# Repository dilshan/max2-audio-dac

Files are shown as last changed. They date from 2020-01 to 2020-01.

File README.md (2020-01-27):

# 24-bit Stereo Audio DAC for Raspberry Pi



MAX-II DAC Module

This is a 24-bit stereo DAC, which is specifically built for Raspberry Pi boards. This R-2R ladder DAC is developing around Intel / Altera *EPM240T100C5N* CPLD.

DAC which described in this repo can directly connect with the I2S interface of Raspberry Pi boards. The recommended supply voltage for this DAC is 5V to 8V.

The *MCP602* opamp of this module is capable to drive headphone directly. An external AF power amplifier must pair with this module to obtain a higher output power.

This repository contains all the files and binaries to build DAC, which including *Intel Quartus* Project files, Raspberry Pi Device Tree Overlays, etc.

This is certified open-source hardware project. All the content of this project are distributed under the terms of the following license:

-   Hardware License: [CC BY 4.0](https://creativecommons.org/licenses/by/4.0/)
-   Software License: [MIT](https://github.com/dilshan/max2-audio-dac/blob/master/LICENSE)
-   [Documentation](https://github.com/dilshan/max2-audio-dac/wiki) License: [CC BY 4.0](https://creativecommons.org/licenses/by/4.0/)

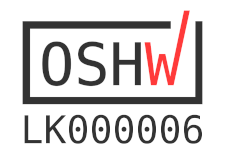
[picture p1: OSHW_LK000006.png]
OSHW-LK000006 (https://certification.oshwa.org/lk000006.html)


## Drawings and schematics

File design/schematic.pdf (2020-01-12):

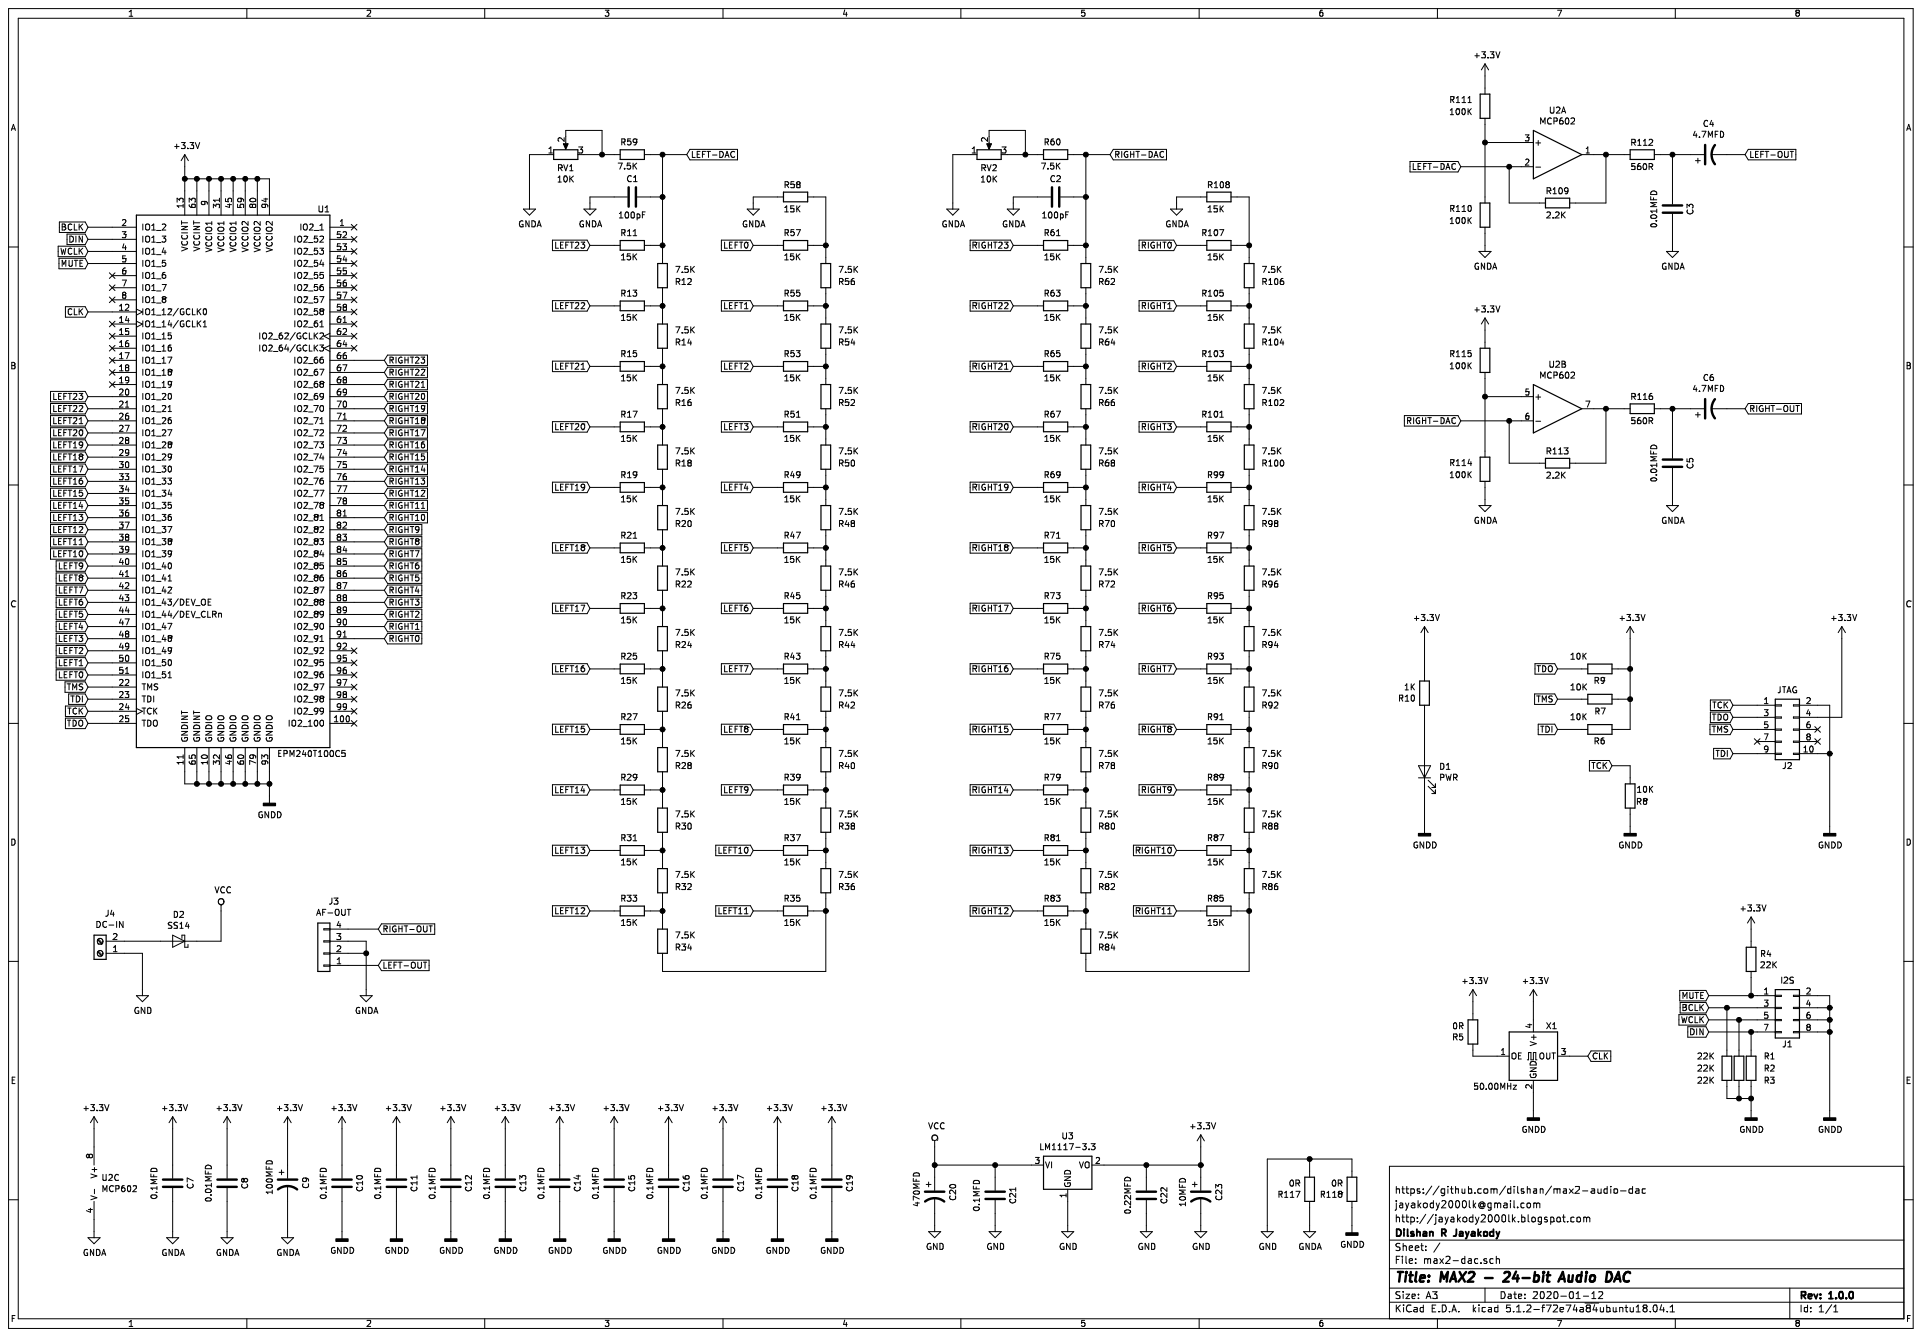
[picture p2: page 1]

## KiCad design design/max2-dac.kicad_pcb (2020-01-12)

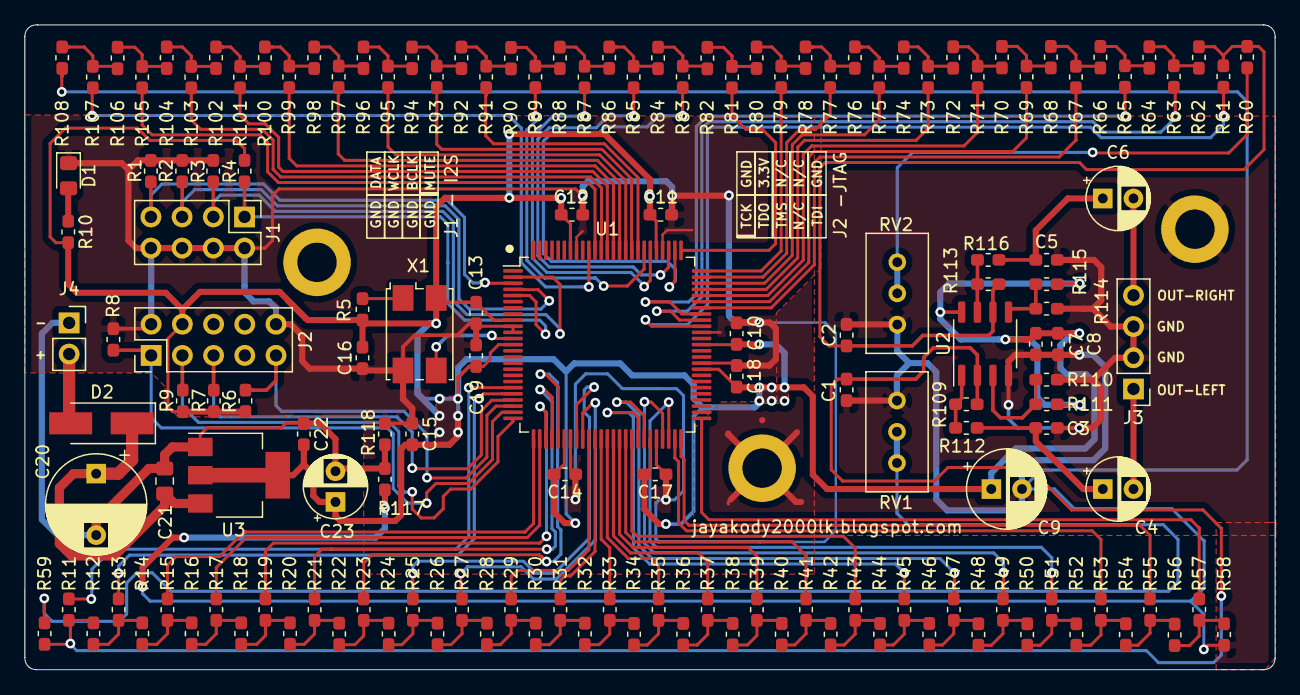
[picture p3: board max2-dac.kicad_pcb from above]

Board: 2 copper layers, 101.8 x 52.5 mm, 156 parts (0 on the bottom side), 123 nets.

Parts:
 : MountingHole_3.2mm_M3_ISO14580_Pad
 #2,  #3: MountingHole_3.2mm_M3_ISO14580_Pad
C1, C2: 100pF; C_0603_1608Metric_Pad1.05x0.95mm_HandSolder
C3, C5, C8: 0.01MFD; C_0603_1608Metric_Pad1.05x0.95mm_HandSolder
C4, C6: 4.7MFD; CP_Radial_D5.0mm_P2.50mm
C7, C10, C11, C12, C13, C14, C15, C16, C17, C18, C19: 0.1MFD; C_0603_1608Metric_Pad1.05x0.95mm_HandSolder
C9: 100MFD; CP_Radial_D6.3mm_P2.50mm
C20: 470MFD; CP_Radial_D8.0mm_P5.00mm
C21: 0.1MFD; C_0805_2012Metric_Pad1.15x1.40mm_HandSolder
C22: 0.22MFD; C_0603_1608Metric_Pad1.05x0.95mm_HandSolder
C23: 10MFD; CP_Radial_D5.0mm_P2.50mm
D1: PWR; LED_0805_2012Metric_Pad1.15x1.40mm_HandSolder
D2: SS14; D_SMA_Handsoldering
J1: I2S; PinHeader_2x04_P2.54mm_Vertical
J2: JTAG; PinHeader_2x05_P2.54mm_Vertical
J3: AF-OUT; PinHeader_1x04_P2.54mm_Vertical
J4: DC-IN; PinSocket_1x02_P2.54mm_Vertical
R1, R2, R3, R4: 22K; R_0603_1608Metric_Pad1.05x0.95mm_HandSolder
R5, R117, R118: 0R; R_0603_1608Metric_Pad1.05x0.95mm_HandSolder
R6, R7, R8, R9: 10K; R_0603_1608Metric_Pad1.05x0.95mm_HandSolder
R10: 1K; R_0603_1608Metric_Pad1.05x0.95mm_HandSolder
R11, R13, R15, R17, R19, R21, R23, R25, R27, R29, R31, R33, R35, R37, R39, R41, R43, R45, R47, R49, R51, R53, R55, R57, R58, R61, R63, R65, R67, R69, R71, R73, R75, R77, R79, R81, R83, R85, R87, R89, R91, R93, R95, R97, R99, R101, R103, R105, R107, R108: 15K; R_0603_1608Metric_Pad1.05x0.95mm_HandSolder
R12, R14, R16, R18, R20, R22, R24, R26, R28, R30, R32, R34, R36, R38, R40, R42, R44, R46, R48, R50, R52, R54, R56, R59, R60, R62, R64, R66, R68, R70, R72, R74, R76, R78, R80, R82, R84, R86, R88, R90, R92, R94, R96, R98, R100, R102, R104, R106: 7.5K; R_0603_1608Metric_Pad1.05x0.95mm_HandSolder
R109, R113: 2.2K; R_0603_1608Metric_Pad1.05x0.95mm_HandSolder
R110, R111, R114, R115: 100K; R_0603_1608Metric_Pad1.05x0.95mm_HandSolder
R112, R116: 560R; R_0603_1608Metric_Pad1.05x0.95mm_HandSolder
RV1, RV2: 10K; Potentiometer_Bourns_3296W_Vertical
U1: EPM240T100C5; LQFP-100_14x14mm_P0.5mm
U2: MCP602; SO-8_3.9x4.9mm_P1.27mm
U3: LM1117-3.3; SOT-223-3_TabPin2
X1: 50.00MHz; Crystal_SMD_7050-4Pin_7.0x5.0mm

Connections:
+3V3: C7.2, C8.2, C9.1, C10.2, C11.2, C12.2, C13.2, C14.2, C15.2, C16.2, C17.2, C18.2, C19.2, C22.2, C23.1, J2.4, R4.1, R5.2, R6.2, R7.1, R9.2, R10.2, R111.2, R115.2, U1.9, U1.13, U1.31, U1.45, U1.59, U1.63, U1.80, U1.94, U2.8, U3.2, X1.4
BCLK: J1.3, R3.1, U1.2
CLK: U1.12, X1.3
DIN: J1.7, R1.1, U1.3
GND: C20.2, C21.1, C22.1, C23.2, J4.1, R117.2, R118.2, U3.1
GNDA: #2.1, #3.1, C1.2, C2.2, C3.1, C5.1, C7.1, C8.1, C9.2, J3.2, J3.3, R58.2, R108.2, R110.1, R114.1, R117.1, RV1.1, RV2.1, U2.4
GNDD: C10.1, C11.1, C12.1, C13.1, C14.1, C15.1, C16.1, C17.1, C18.1, C19.1, D1.1, J1.2, J1.4, J1.6, J1.8, J2.2, J2.10, R1.2, R2.2, R3.2, R8.1, R118.1, U1.10, U1.11, U1.32, U1.46, U1.60, U1.65, U1.79, U1.93, X1.2
LEFT0: R57.1, U1.51
LEFT1: R55.1, U1.50
LEFT2: R53.1, U1.49
LEFT3: R51.1, U1.48
LEFT4: R49.1, U1.47
LEFT5: R47.1, U1.44
LEFT6: R45.1, U1.43
LEFT7: R43.1, U1.42
LEFT8: R41.1, U1.41
LEFT9: R39.1, U1.40
LEFT10: R37.1, U1.39
LEFT11: R35.1, U1.38
LEFT12: R33.1, U1.37
LEFT13: R31.1, U1.36
LEFT14: R29.1, U1.35
LEFT15: R27.1, U1.34
LEFT16: R25.1, U1.33
LEFT17: R23.1, U1.30
LEFT18: R21.1, U1.29
LEFT19: R19.1, U1.28
LEFT20: R17.1, U1.27
LEFT21: R15.1, U1.26
LEFT22: R13.1, U1.21
LEFT23: R11.1, U1.20
LEFT-DAC: C1.1, R11.2, R12.1, R59.2, R109.2, U2.2
LEFT-OUT: C4.2, J3.1
MUTE: J1.1, R4.2, U1.5
unnamed: C3.2, C4.1, R112.1
unnamed: C5.2, C6.1, R116.1
unnamed: D1.2, R10.1
unnamed: D2.2, J4.2
unnamed: R5.1, X1.1
unnamed: R12.2, R13.2, R14.1
unnamed: R14.2, R15.2, R16.1
unnamed: R16.2, R17.2, R18.1
unnamed: R18.2, R19.2, R20.1
unnamed: R20.2, R21.2, R22.1
unnamed: R22.2, R23.2, R24.1
unnamed: R24.2, R25.2, R26.1
unnamed: R26.2, R27.2, R28.1
unnamed: R28.2, R29.2, R30.1
unnamed: R30.2, R31.2, R32.1
unnamed: R32.2, R33.2, R34.1
unnamed: R34.2, R35.2, R36.2
unnamed: R36.1, R37.2, R38.2
unnamed: R38.1, R39.2, R40.2
unnamed: R40.1, R41.2, R42.2
unnamed: R42.1, R43.2, R44.2
unnamed: R44.1, R45.2, R46.2
unnamed: R46.1, R47.2, R48.2
unnamed: R48.1, R49.2, R50.2
unnamed: R50.1, R51.2, R52.2
unnamed: R52.1, R53.2, R54.2
unnamed: R54.1, R55.2, R56.2
unnamed: R56.1, R57.2, R58.1
unnamed: R59.1, RV1.2, RV1.3
unnamed: R60.1, RV2.2, RV2.3
unnamed: R62.2, R63.2, R64.1
unnamed: R64.2, R65.2, R66.1
unnamed: R66.2, R67.2, R68.1
unnamed: R68.2, R69.2, R70.1
unnamed: R70.2, R71.2, R72.1
unnamed: R72.2, R73.2, R74.1
unnamed: R74.2, R75.2, R76.1
unnamed: R76.2, R77.2, R78.1
unnamed: R78.2, R79.2, R80.1
unnamed: R80.2, R81.2, R82.1
unnamed: R82.2, R83.2, R84.1
unnamed: R84.2, R85.2, R86.2
unnamed: R86.1, R87.2, R88.2
unnamed: R88.1, R89.2, R90.2
unnamed: R90.1, R91.2, R92.2
unnamed: R92.1, R93.2, R94.2
unnamed: R94.1, R95.2, R96.2
unnamed: R96.1, R97.2, R98.2
unnamed: R100.1, R101.2, R102.2
unnamed: R98.1, R99.2, R100.2
unnamed: R102.1, R103.2, R104.2
unnamed: R104.1, R105.2, R106.2
unnamed: R106.1, R107.2, R108.1
unnamed: R109.1, R112.2, U2.1
unnamed: R110.2, R111.1, U2.3
unnamed: R113.1, R116.2, U2.7
unnamed: R114.2, R115.1, U2.5
RIGHT0: R107.1, U1.91
RIGHT1: R105.1, U1.90
RIGHT2: R103.1, U1.89
RIGHT3: R101.1, U1.88
RIGHT4: R99.1, U1.87
RIGHT5: R97.1, U1.86
RIGHT6: R95.1, U1.85
RIGHT7: R93.1, U1.84
RIGHT8: R91.1, U1.83
RIGHT9: R89.1, U1.82
RIGHT10: R87.1, U1.81
RIGHT11: R85.1, U1.78
RIGHT12: R83.1, U1.77
RIGHT13: R81.1, U1.76
RIGHT14: R79.1, U1.75
RIGHT15: R77.1, U1.74
RIGHT16: R75.1, U1.73
RIGHT17: R73.1, U1.72
RIGHT18: R71.1, U1.71
RIGHT19: R69.1, U1.70
RIGHT20: R67.1, U1.69
RIGHT21: R65.1, U1.68
RIGHT22: R63.1, U1.67
RIGHT23: R61.1, U1.66
RIGHT-DAC: C2.1, R60.2, R61.2, R62.1, R113.2, U2.6
RIGHT-OUT: C6.2, J3.4
TCK: J2.1, R8.2, U1.24
TDI: J2.9, R6.1, U1.23
TDO: J2.3, R9.1, U1.25
TMS: J2.5, R7.2, U1.22
VCC: C20.1, C21.2, D2.1, U3.3
WCLK: J1.5, R2.1, U1.4

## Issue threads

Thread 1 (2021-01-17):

question

munjeni, 2021-01-17:
Hallo!

I very interested in building some variants and want to ask for your experience if possible. I have found 3 variants:

1. https://audiophilediyer.com/discrete-r-2r-dac-hat-for-raspberry-pi/
2. http://puredsd.ru
3. http://www.audiodesignguide.com/DSC2/index.html

Can you tell me did you triend all 3 variants and what you think in your opinions is the best one (related to r2r implementation only)? Thanks for response!

smdjeff, 2022-09-11:
Ladder DACs go back to at least the 1950s.
The Pi hat looks to be the cleanest implementation if you're after audio.
The other two versions use  595s as IO expanders so they might be related.
And this one by @dilshan is a bit simpler(cleaner) as it uses GPIOs directly.

munjeni, 2023-01-14:
I think r2r is at the last, the better one is that which have current mode moving average implementation as done in DSC dac, a lot less noise in comparation to r2r technology, but it reguire DSD bitstream. We have done direct digital power dac DDPD with success and amazing sound, more info https://www.diyaudio.com/community/threads/ct7302pl.357501/page-4

natil79, 2024-07-27:
Hi, nice work,, I would like to build it, but I would like to use it whitout Raspberry pi, could you tell me what frequency I2S source it can handle?

Thank you for your help!

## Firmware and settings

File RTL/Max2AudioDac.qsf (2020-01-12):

# -------------------------------------------------------------------------- #
#
# Copyright (C) 2018  Intel Corporation. All rights reserved.
# Your use of Intel Corporation's design tools, logic functions 
# and other software and tools, and its AMPP partner logic 
# functions, and any output files from any of the foregoing 
# (including device programming or simulation files), and any 
# associated documentation or information are expressly subject 
# to the terms and conditions of the Intel Program License 
# Subscription Agreement, the Intel Quartus Prime License Agreement,
# the Intel FPGA IP License Agreement, or other applicable license
# agreement, including, without limitation, that your use is for
# the sole purpose of programming logic devices manufactured by
# Intel and sold by Intel or its authorized distributors.  Please
# refer to the applicable agreement for further details.
#
# -------------------------------------------------------------------------- #
#
# Quartus Prime
# Version 18.1.0 Build 625 09/12/2018 SJ Lite Edition
# Date created = 13:50:59  August 08, 2019
#
# -------------------------------------------------------------------------- #
#
# Notes:
#
# 1) The default values for assignments are stored in the file:
#		Max2AudioDac_assignment_defaults.qdf
#    If this file doesn't exist, see file:
#		assignment_defaults.qdf
#
# 2) Altera recommends that you do not modify this file. This
#    file is updated automatically by the Quartus Prime software
#    and any changes you make may be lost or overwritten.
#
# -------------------------------------------------------------------------- #


set_global_assignment -name FAMILY "MAX II"
set_global_assignment -name DEVICE EPM240T100C5
set_global_assignment -name TOP_LEVEL_ENTITY Max2AudioDac
set_global_assignment -name ORIGINAL_QUARTUS_VERSION 18.1.0
set_global_assignment -name PROJECT_CREATION_TIME_DATE "13:50:59  AUGUST 08, 2019"
set_global_assignment -name LAST_QUARTUS_VERSION "18.1.0 Lite Edition"
set_global_assignment -name PROJECT_OUTPUT_DIRECTORY output_files
set_global_assignment -name MIN_CORE_JUNCTION_TEMP 0
set_global_assignment -name MAX_CORE_JUNCTION_TEMP 85
set_global_assignment -name ERROR_CHECK_FREQUENCY_DIVISOR "-1"
set_global_assignment -name POWER_EXT_SUPPLY_VOLTAGE_TO_REGULATOR 3.3V
set_global_assignment -name EDA_SIMULATION_TOOL "ModelSim-Altera (Verilog)"
set_global_assignment -name EDA_TIME_SCALE "1 ps" -section_id eda_simulation
set_global_assignment -name EDA_OUTPUT_DATA_FORMAT "VERILOG HDL" -section_id eda_simulation
set_global_assignment -name VERILOG_FILE Max2AudioDac.v
set_global_assignment -name POWER_PRESET_COOLING_SOLUTION "NO HEAT SINK WITH STILL AIR"
set_global_assignment -name VECTOR_WAVEFORM_FILE waveform.vwf
set_location_assignment PIN_51 -to lout[0]
set_location_assignment PIN_2 -to bclk
set_location_assignment PIN_3 -to din
set_location_assignment PIN_34 -to lout[15]
set_instance_assignment -name IO_STANDARD "3.3-V LVCMOS" -to lout[14]
set_instance_assignment -name IO_STANDARD "3.3-V LVCMOS" -to lout[15]
set_instance_assignment -name IO_STANDARD "3.3-V LVCMOS" -to din
set_instance_assignment -name IO_STANDARD "3.3-V LVCMOS" -to bclk
set_instance_assignment -name IO_STANDARD "3.3-V LVCMOS" -to wclk
set_instance_assignment -name IO_STANDARD "3.3-V LVCMOS" -to rout[1]
set_instance_assignment -name IO_STANDARD "3.3-V LVCMOS" -to lout[13]
set_instance_assignment -name IO_STANDARD "3.3-V LVCMOS" -to lout[12]
set_instance_assignment -name IO_STANDARD "3.3-V LVCMOS" -to lout[11]
set_instance_assignment -name IO_STANDARD "3.3-V LVCMOS" -to lout[10]
set_instance_assignment -name IO_STANDARD "3.3-V LVCMOS" -to lout[9]
set_location_assignment PIN_35 -to lout[14]
set_location_assignment PIN_36 -to lout[13]
set_location_assignment PIN_37 -to lout[12]
set_location_assignment PIN_38 -to lout[11]
set_location_assignment PIN_39 -to lout[10]
set_location_assignment PIN_40 -to lout[9]
set_location_assignment PIN_41 -to lout[8]
set_location_assignment PIN_42 -to lout[7]
set_location_assignment PIN_43 -to lout[6]
set_location_assignment PIN_44 -to lout[5]
set_location_assignment PIN_47 -to lout[4]
set_location_assignment PIN_48 -to lout[3]
set_location_assignment PIN_49 -to lout[2]
set_location_assignment PIN_50 -to lout[1]
set_location_assignment PIN_74 -to rout[15]
set_location_assignment PIN_75 -to rout[14]
set_location_assignment PIN_76 -to rout[13]
set_location_assignment PIN_77 -to rout[12]
set_location_assignment PIN_78 -to rout[11]
set_location_assignment PIN_81 -to rout[10]
set_location_assignment PIN_82 -to rout[9]
set_location_assignment PIN_84 -to rout[7]
set_location_assignment PIN_83 -to rout[8]
set_location_assignment PIN_86 -to rout[5]
set_location_assignment PIN_85 -to rout[6]
set_location_assignment PIN_87 -to rout[4]
set_location_assignment PIN_88 -to rout[3]
set_location_assignment PIN_89 -to rout[2]
set_location_assignment PIN_90 -to rout[1]
set_location_assignment PIN_91 -to rout[0]
set_location_assignment PIN_4 -to wclk
set_location_assignment PIN_33 -to lout[16]
set_location_assignment PIN_30 -to lout[17]
set_location_assignment PIN_29 -to lout[18]
set_location_assignment PIN_28 -to lout[19]
set_location_assignment PIN_27 -to lout[20]
set_location_assignment PIN_26 -to lout[21]
set_location_assignment PIN_21 -to lout[22]
set_location_assignment PIN_20 -to lout[23]
set_location_assignment PIN_73 -to rout[16]
set_location_assignment PIN_72 -to rout[17]
set_location_assignment PIN_71 -to rout[18]
set_location_assignment PIN_70 -to rout[19]
set_location_assignment PIN_69 -to rout[20]
set_location_assignment PIN_68 -to rout[21]
set_location_assignment PIN_67 -to rout[22]
set_location_assignment PIN_66 -to rout[23]
set_instance_assignment -name IO_STANDARD "3.3-V LVCMOS" -to lout[23]
set_instance_assignment -name IO_STANDARD "3.3-V LVCMOS" -to lout[22]
set_instance_assignment -name IO_STANDARD "3.3-V LVCMOS" -to lout[21]
set_instance_assignment -name IO_STANDARD "3.3-V LVCMOS" -to lout[20]
set_instance_assignment -name IO_STANDARD "3.3-V LVCMOS" -to lout[19]
set_instance_assignment -name IO_STANDARD "3.3-V LVCMOS" -to lout[18]
set_instance_assignment -name IO_STANDARD "3.3-V LVCMOS" -to lout[17]
set_instance_assignment -name IO_STANDARD "3.3-V LVCMOS" -to lout[16]
set_instance_assignment -name IO_STANDARD "3.3-V LVCMOS" -to lout[8]
set_instance_assignment -name IO_STANDARD "3.3-V LVCMOS" -to lout[7]
set_instance_assignment -name IO_STANDARD "3.3-V LVCMOS" -to lout[6]
set_instance_assignment -name IO_STANDARD "3.3-V LVCMOS" -to lout[5]
set_instance_assignment -name IO_STANDARD "3.3-V LVCMOS" -to lout[4]
set_instance_assignment -name IO_STANDARD "3.3-V LVCMOS" -to lout[3]
set_instance_assignment -name IO_STANDARD "3.3-V LVCMOS" -to lout[2]
set_instance_assignment -name IO_STANDARD "3.3-V LVCMOS" -to lout[1]
set_instance_assignment -name IO_STANDARD "3.3-V LVCMOS" -to lout[0]
set_instance_assignment -name IO_STANDARD "3.3-V LVCMOS" -to lout
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

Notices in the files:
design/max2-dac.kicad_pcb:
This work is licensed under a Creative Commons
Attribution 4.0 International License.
